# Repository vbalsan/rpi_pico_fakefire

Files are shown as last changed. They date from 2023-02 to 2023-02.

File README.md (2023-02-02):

# rpi_pico_fakefire

The electric fireplace project.

Main goal is to have this :
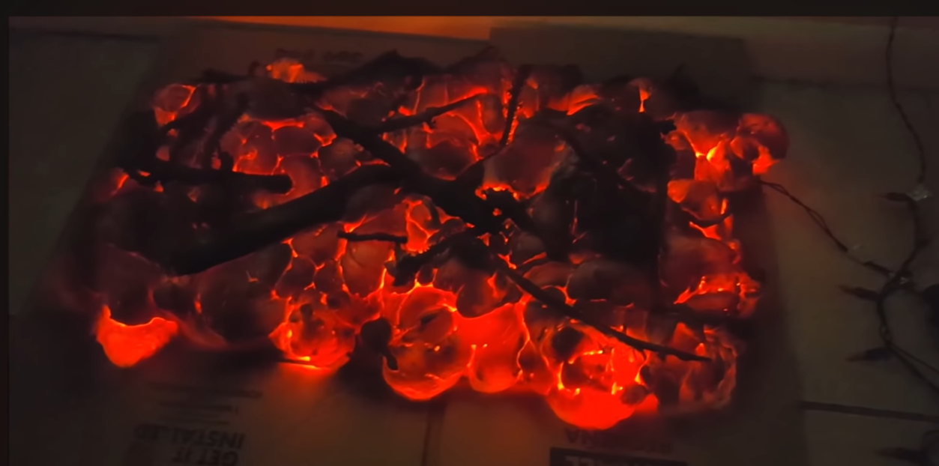
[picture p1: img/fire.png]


But with flickering, and sound, and little bonus like color control...
Idea came after landlord decided that we could not use our fireplace anymore, and didn't want to pay 400-500 bucks for an electric one.

## **How to ?**
The trick is to use foam (the kind you can find at reno store for filling cracks and holes) with lights, of course since just simple Christmas lights don't twinkle, we need to use a microcontroller with leds.

After several tests, I abandonned the idea of leds with PWM, for a led strip, much better, but the ws2812/ws2811 needs special timings.
Used ATtiny85 at the beginning since I had plenty, but the low-power 10MHz versions cannot manage the 800 or 400kHz ws2811 chips plus the calculation for the lights.

As I found, a raspberry pico is much better for the project, the PIOs can decipher IR reception without stopping the stream (a complete IR frame is around 40ms) , and I could write a PIO-assembly program to manage the lights within the main C file.
Could have gone with the rp2040 only, but for 4$...

## **What is there in the end ?**
Final board contains :
- a 12V / 5V converter, switching DC-DC
- a MOSFET to control 12V supply to the strip
- NAND gate for 3.3V to 5V conversion (could have done with diode)
- a DFPlayer for the sound
- a PAM8403 for amplification (not really necessary for one 4 Ohm speaker)
- TSOP1838B IR receiver
- a raspberry pico for all the logic
- a 4 Ohm speaker
- several old 5mm leds and through hole resistor for a retro look

## **Analysis for the signal controlling the ws2811 :**

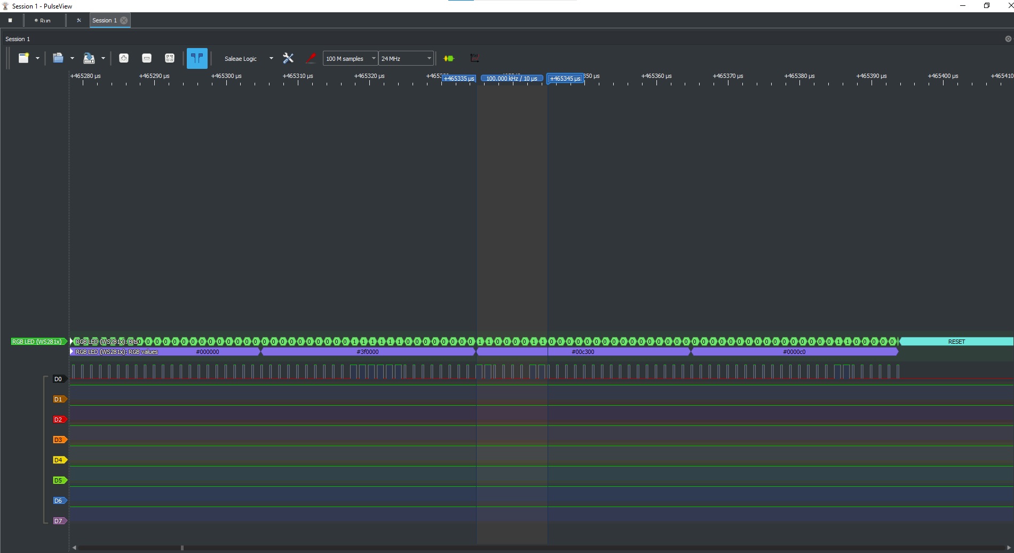
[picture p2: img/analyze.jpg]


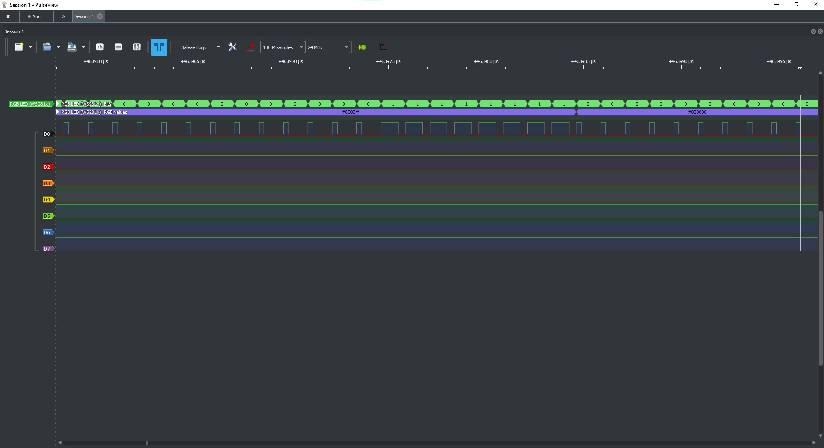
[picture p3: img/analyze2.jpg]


This gave me the occasion to create libraries for the IR receiver (TSOP1838B) and the ws2811.

## **The PCB :**
First prototype was on a... prototype board, but decided to go real PCB with Kicad and JLCPCB, result :

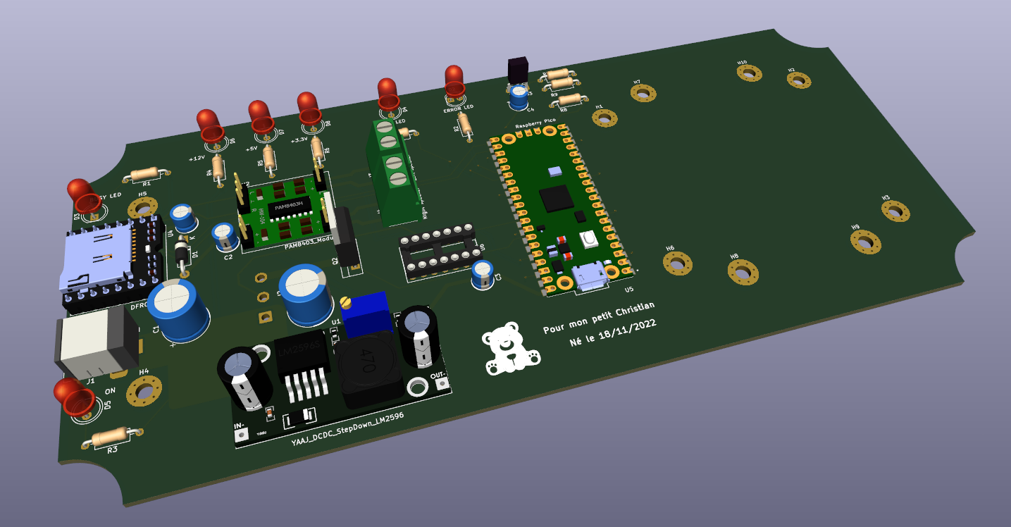
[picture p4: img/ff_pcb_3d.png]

PCB in 3D on Kicad

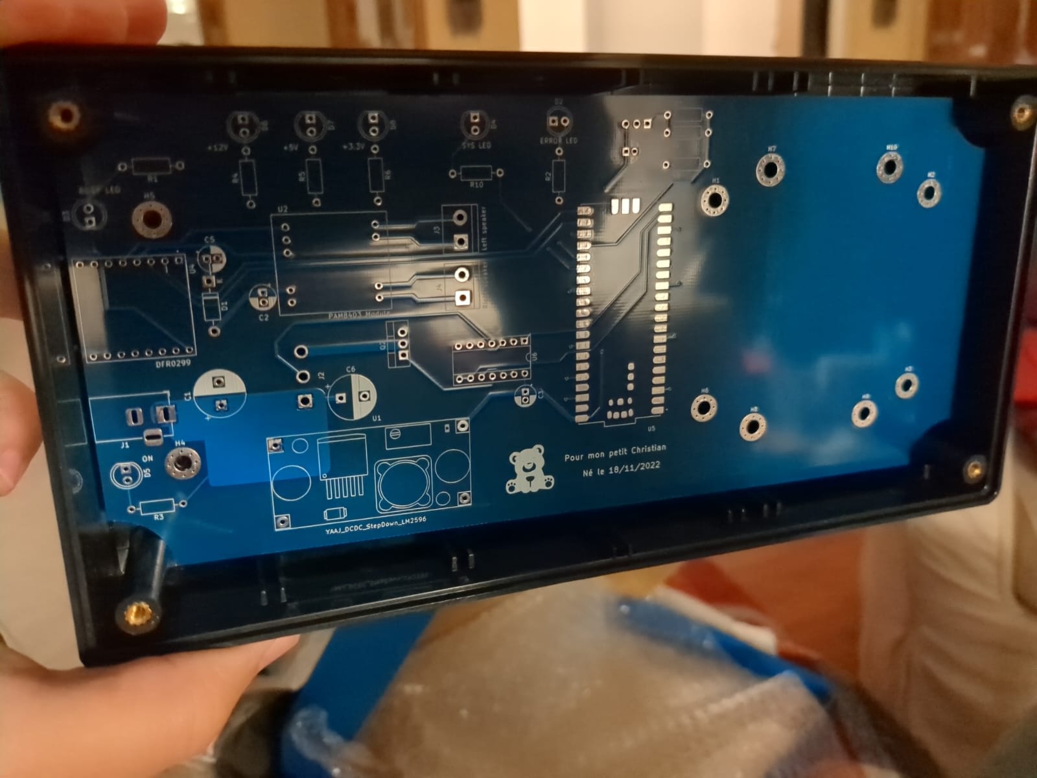
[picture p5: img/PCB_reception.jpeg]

PCB received

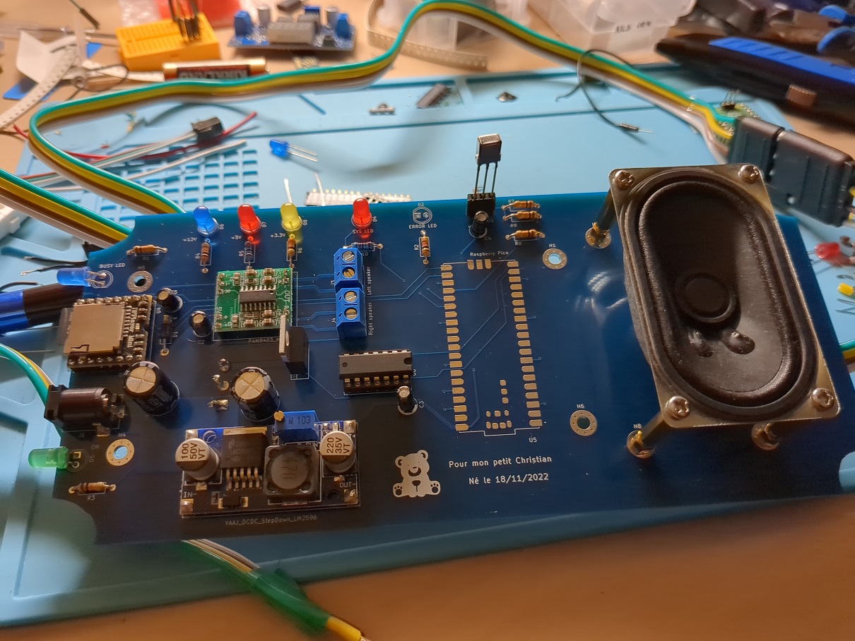
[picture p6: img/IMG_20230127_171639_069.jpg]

PCB almost fully populated

## **What now ?**
So far, project is continuing... There are issues on IR reception, probably using 3 resistors to decrease the voltage from 5V to 3.3 for GPIO was not a good idea.
Need to make some tests as I could not find the input impedance of the pico GPIO.

## **Pro/cons**

- I've put 16V capacitor for the 12V supply, it's bad, but it was what I had in my drawer
- Forgot to put a UART/serial port, quite a mess to debug even if I could use the SWD
- Didn't add filtering for the sound, not specialist in this, right now the cracking wood sound is more like frying oil.

## **Mapping buttons : **

on off (top)                    menu
BA45FF00                        B847FF00

Test            +               return
BB44FF00        BF40FF00        BC43FF00

<<              play            >>
F807FF00        EA15FF00        F609FF00

0               -               C
E916FF00        E619FF00        F20DFF00

1               2               3
F30CFF00        E718FF00        A15EFF00

4               5               6
F708FF00        E31CFF00        A55AFF00

7               8               9
BD42FF00        AD52FF00        B54AFF00

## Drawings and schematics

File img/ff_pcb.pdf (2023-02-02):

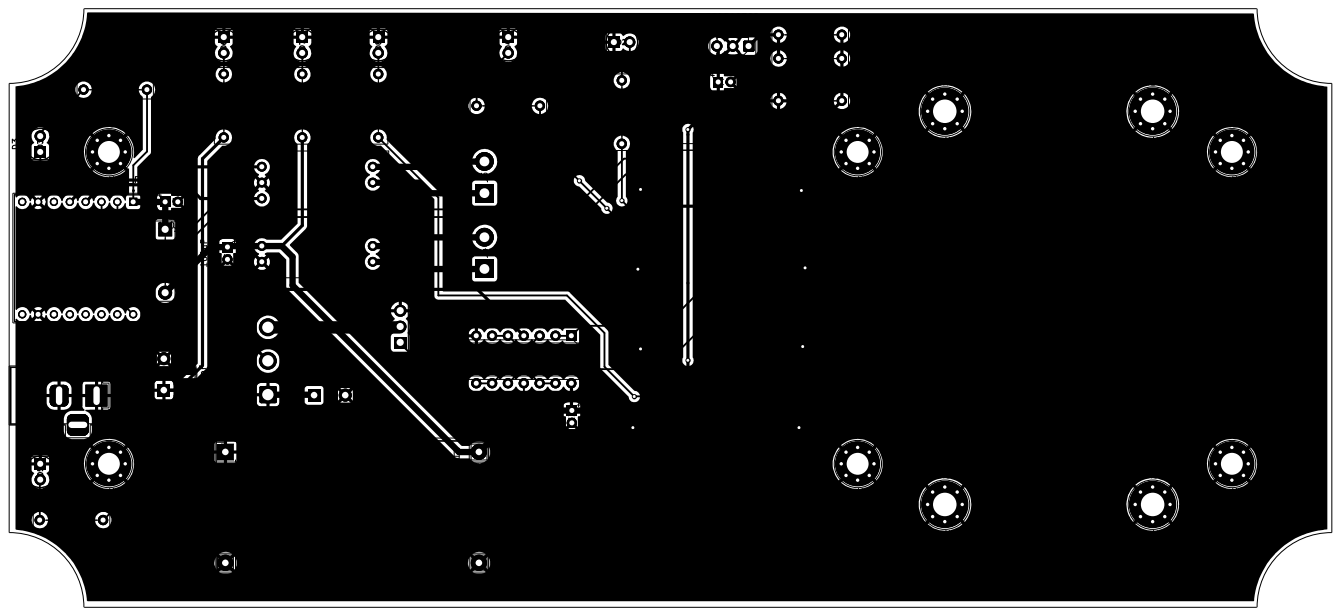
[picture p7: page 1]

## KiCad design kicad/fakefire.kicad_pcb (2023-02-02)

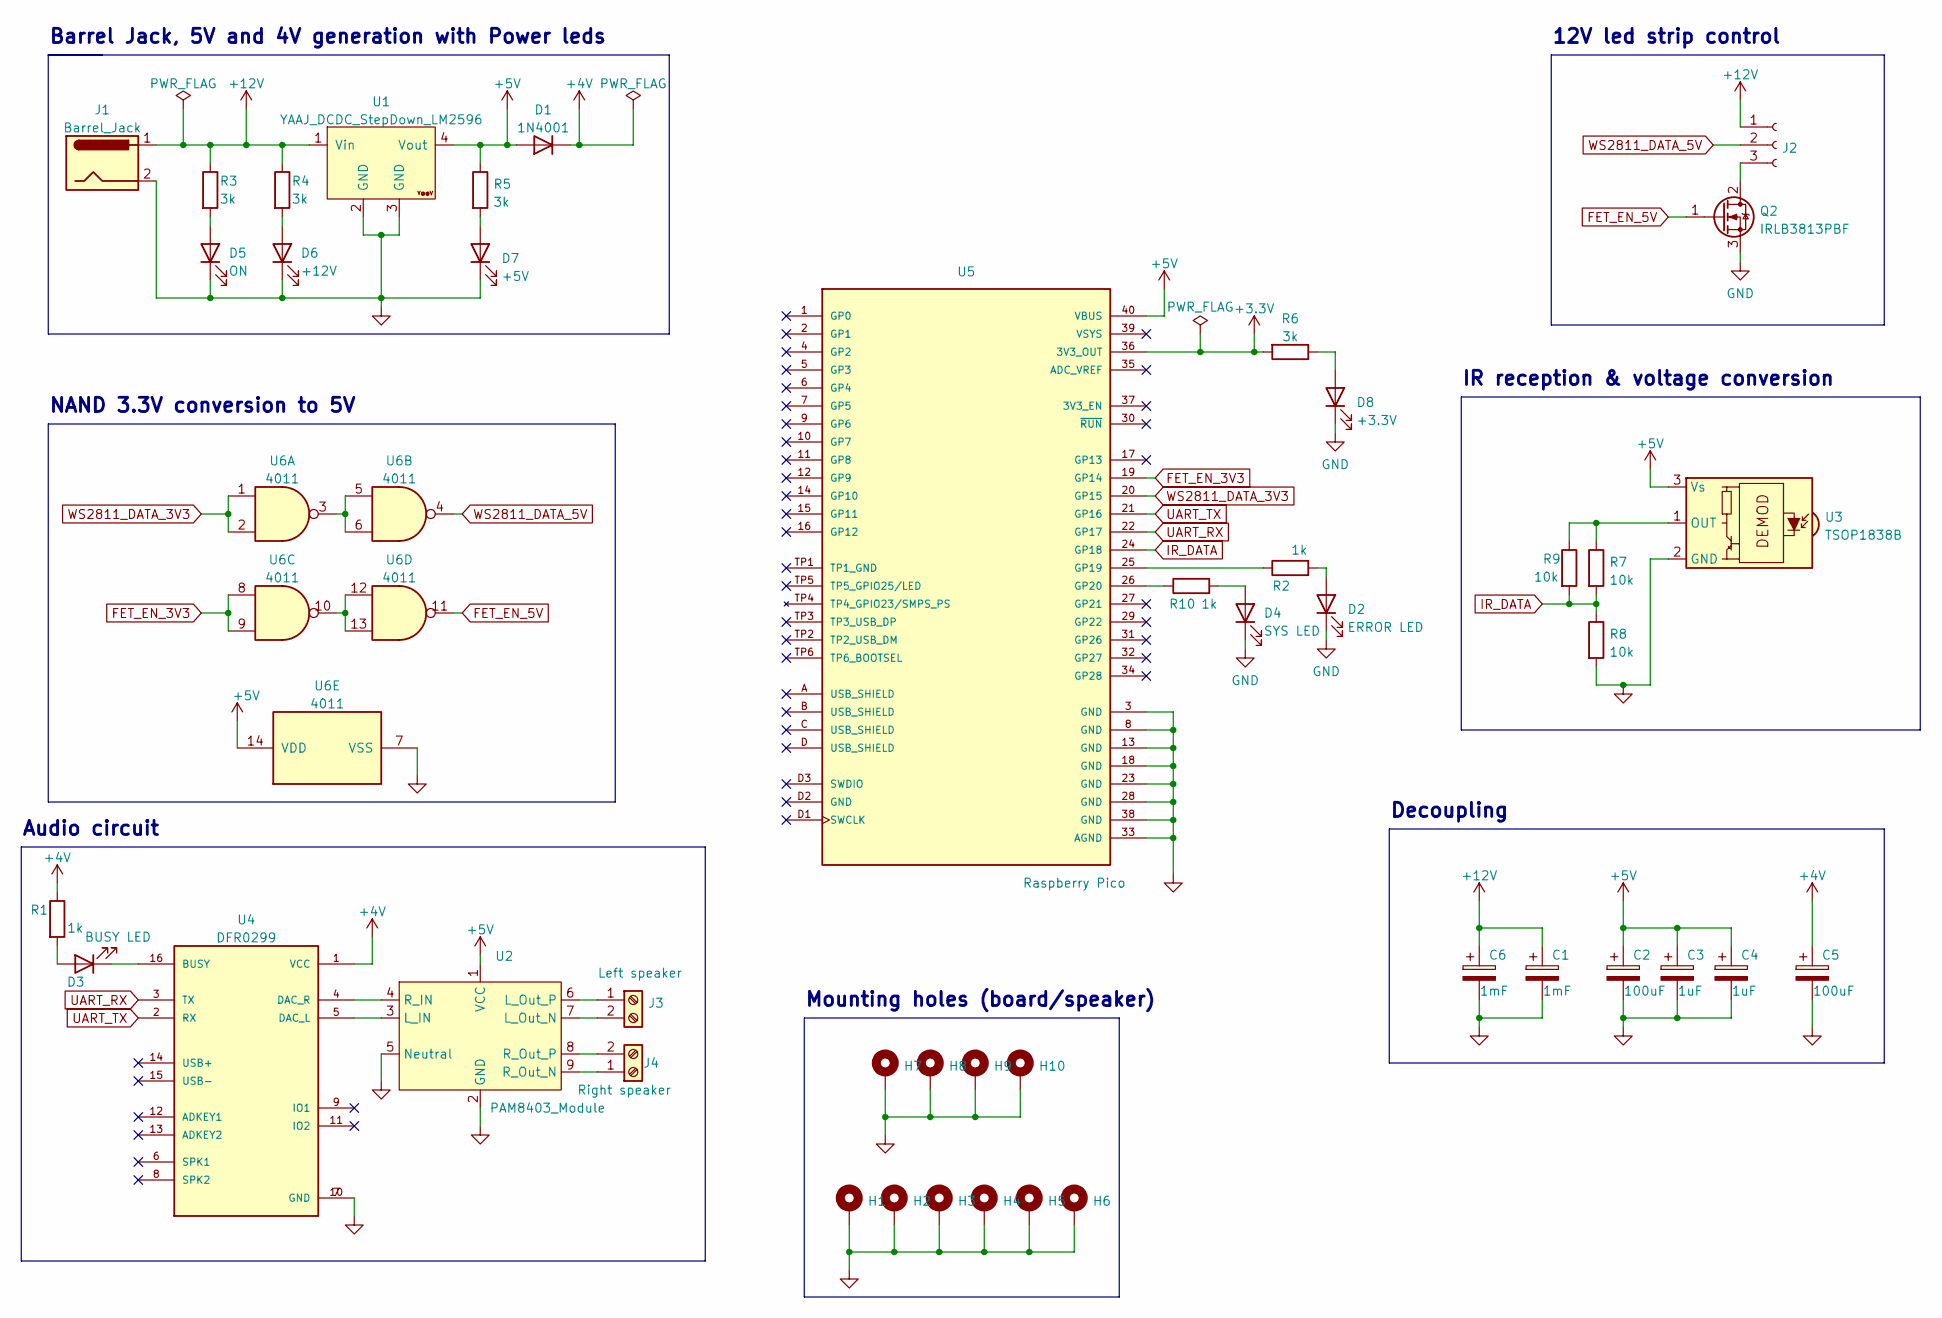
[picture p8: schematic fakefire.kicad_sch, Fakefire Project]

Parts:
C1, C6: 1mF; CP_Radial_D10.0mm_P5.00mm
C2, C5: 100uF; CP_Radial_D5.0mm_P2.00mm
C3, C4: 1uF; CP_Radial_D5.0mm_P2.00mm
D1: 1N4001; D_DO-41_SOD81_P10.16mm_Horizontal
D2: ERROR LED; LED_D5.0mm
D3: BUSY LED; LED_D5.0mm
D4: SYS LED; LED_D5.0mm
D5: ON; LED_D5.0mm
D6: +12V; LED_D5.0mm
D7: +5V; LED_D5.0mm
D8: +3.3V; LED_D5.0mm
H1, H2, H3, H4, H5, H6: MountingHole_Pad; MountingHole_3.5mm_Pad_Via
H7, H8, H9, H10: MountingHole_Pad; MountingHole_3.7mm_Pad_Via
J1: Barrel_Jack; BarrelJack_Horizontal
J2: Conn_01x03_Female; SolderWire-1sqmm_1x03_P5.4mm_D1.4mm_OD2.7mm
J3: Left speaker; TerminalBlock_bornier-2_P5.08mm
J4: Right speaker; TerminalBlock_bornier-2_P5.08mm
Q2: IRLB3813PBF; TO-220-3_Vertical
R1, R2, R10: 1k; R_Axial_DIN0207_L6.3mm_D2.5mm_P10.16mm_Horizontal
R3, R4, R5, R6: 3k; R_Axial_DIN0207_L6.3mm_D2.5mm_P10.16mm_Horizontal
R7, R8, R9: 10k; R_Axial_DIN0207_L6.3mm_D2.5mm_P10.16mm_Horizontal
U1: YAAJ_DCDC_StepDown_LM2596
U2: PAM8403_Module
U3: TSOP1838B; Vishay_MINICAST-3Pin
U4: DFR0299; MODULE_DFR0299
U5: Raspberry Pico; Pico; PARTREV 1.6
U6: 4011; DIP-14_W7.62mm_Socket

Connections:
+3.3V: R6.2, U5.36 (3V3_OUT)
+4V: C5.1, D1.1 (K), R1.1, U4.1 (VCC)
+5V: C2.1, C3.1, C4.1, D1.2 (A), R5.1, U1.4 (Vout), U2.1 (VCC), U3.3 (Vs), U5.40 (VBUS), U6.14 (VDD)
+12V: C1.1, C6.1, J1.1, J2.1, R3.1, R4.1, U1.1 (Vin)
FET_EN_3V3: U5.19 (GP14), U6.8, U6.9
FET_EN_5V: Q2.1 (G), U6.11
GND: C1.2, C2.2, C3.2, C4.2, C5.2, C6.2, D2.1 (K), D4.1 (K), D5.1 (K), D6.1 (K), D7.1 (K), D8.1 (K), H1.1, H2.1, H3.1, H4.1, H5.1, H6.1, H7.1, H8.1, H9.1, H10.1, J1.2, Q2.3 (S), R8.2, U1.2 (GND), U1.3 (GND), U2.2 (GND), U2.5 (Neutral), U3.2 (GND), U4.7 (GND), U4.10 (GND), U5.3 (GND), U5.8 (GND), U5.13 (GND), U5.18 (GND), U5.23 (GND), U5.28 (GND), U5.33 (AGND), U5.38 (GND), U6.7 (VSS)
IR_DATA: R7.2, R8.1, R9.2, U5.24 (GP18)
unnamed: D2.2 (A), R2.2
unnamed: D3.1 (K), U4.16 (BUSY)
unnamed: D3.2 (A), R1.2
unnamed: D4.2 (A), R10.2
unnamed: D5.2 (A), R3.2
unnamed: D6.2 (A), R4.2
unnamed: D7.2 (A), R5.2
unnamed: D8.2 (A), R6.1
unnamed: J2.3, Q2.2 (D)
unnamed: J3.1, U2.6 (L_Out_P)
unnamed: J3.2, U2.7 (L_Out_N)
unnamed: J4.1, U2.9 (R_Out_N)
unnamed: J4.2, U2.8 (R_Out_P)
unnamed: R2.1, U5.25 (GP19)
unnamed: R7.1, R9.1, U3.1 (OUT)
unnamed: U2.3 (L_IN), U4.5 (DAC_L)
unnamed: U2.4 (R_IN), U4.4 (DAC_R)
unnamed: R10.1, U5.26 (GP20)
unnamed: U6.3, U6.5, U6.6
unnamed: U6.10, U6.12, U6.13
UART_RX: U4.3 (TX), U5.22 (GP17)
UART_TX: U4.2 (RX), U5.21 (GP16)
WS2811_DATA_3V3: U5.20 (GP15), U6.1, U6.2
WS2811_DATA_5V: J2.2, U6.4

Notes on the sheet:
12V led strip control
IR reception & voltage conversion
Audio circuit
Barrel Jack, 5V and 4V generation with Power leds
Mounting holes (board/speaker)
Decoupling
NAND 3.3V conversion to 5V

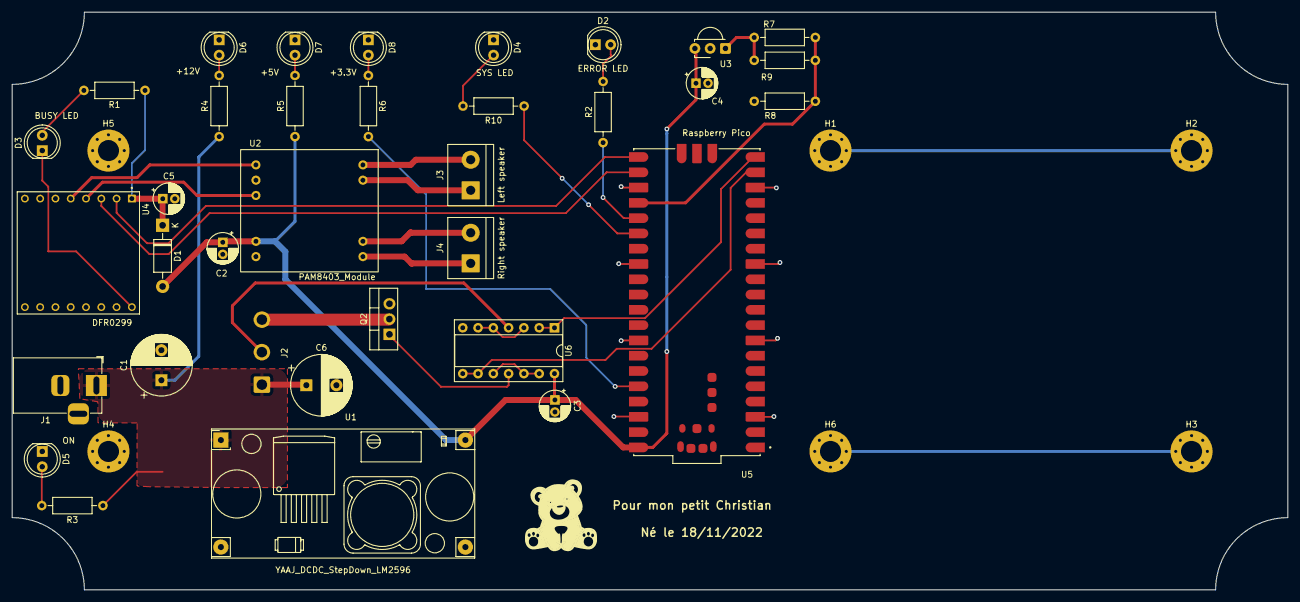
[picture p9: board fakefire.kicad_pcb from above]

Board: 2 copper layers, 212.0 x 96.0 mm, 41 parts (0 on the bottom side), 32 nets.

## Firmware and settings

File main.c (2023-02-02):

/**
 */


#include <stdio.h>
#include <stdlib.h>

#include "globals.h"
#include "values.h"

#include "pico/stdlib.h"

#include "nec_receive_library/nec_receive.h"
#include "DFPlayer_library/DFPlayerCommands.h"
#include "ws2811_library/ws2811.h"

uint8_t main_val   = 0;             // main_val is equal to the current value in array
uint8_t main_val10 = 0;             // same as main_val but divided by 10
uint8_t main_val50 = 0;             // same as main_val but divided by 50

uint8_t *pGreenVal;                 // Pointer to the value of green (can be full, /10 or /50)
uint8_t *pRedVal;                   // Pointer to the value of red (can be full, /10 or /50)
uint8_t *pBlueVal;                  // Pointer to the value of blue (can be full, /10 or /50)

void SetGreen()
{
    pRedVal = &main_val10;
    pGreenVal = &main_val;    
    pBlueVal = &main_val50;
}

void SetRed()
{
    pGreenVal = &main_val10;
    pRedVal = &main_val;    
    pBlueVal = &main_val50;
}

void SetBlue()
{
    pGreenVal = &main_val10;
    pBlueVal = &main_val;    
    pRedVal = &main_val50;
}

void set_power_leds(bool mosfet_val)  
{
    if (mosfet_val)
    {
        gpio_put(FET_PIN, 1);
    }
    else
    {
        for (uint8_t i = 0; i < NUM_PIXELS; i++) 
        {          
            put_pixel(0);
        }
        gpio_put(FET_PIN, 0);
    }
}


void process_rx_data(uint8_t rx_data)
{
    switch (rx_data)
    {
    case 0x45:                      // on off                        
        SysActive = !SysActive;

        if(SysActive)
        {
            gpio_put(SYSLED, 1);
            set_power_leds(true);   // turn on MOSFET
            sleep_ms(20);
            SetRed();
            DFP_Main_Start();            
        }
        else 
        {
            gpio_put(SYSLED, 0);
            set_power_leds(false);  // stop MOSFET
            DFP_Main_Stop();
        }        
        break;

    case 0x44:                      // Test
        SetGreen(); 
        DFP_PlayTrack(1,2);
        break;

    case 0x40:                      // +
        DFP_IncreaseVolume();
        break;

    case 0x19:                      // -
        DFP_DecreaseVolume();
        break;

    case 0x47:                      // menu
        break;

    case 0x07:                      // <<
        DFP_PreviousTrack();
        break;

    case 0x09:                      // >>
        DFP_NextTrack();
        break;

    case 0x43:                      // return
        break;
    case 0x0D:                      // C
        break;

    case 0x15:                      // play
        DFP_PlayOrPause();
        break;

    case 0x16:                      // 0
        SetRed();
        break;
    case 0x0C:                      // 1
        SetBlue();
        break;
    case 0x18:                      // 2
        SetGreen();
        break;
    case 0x5E:                      // 3
        SetRed();
        break;
    case 0x08:                      // 4
        SetRed();
        break;
    case 0x1C:                      // 5
        SetRed();
        break;
    case 0x5A:                      // 6
        SetRed();
        break;
    case 0x42:                      // 7
        SetRed();
        break;
    case 0x52:                      // 8
        SetRed();
        break;
    case 0x4A:                      // 9
        SetGreen(); 
        DFP_PlayTrack(1,3);
        break;
    
    default:
        break;
    }
}

void ir_receive_and_exec()
{
    uint32_t rx_frame;                          // For IR frame, 32 bits message    
    uint8_t  rx_address, rx_data;               // received IR data

    while (!is_fifo_empty())
    {
        rx_frame = get_message();
        if (nec_decode_frame(rx_frame, &rx_address, &rx_data)) 
        {
            if(rx_address == 0x00)
            {
                process_rx_data(rx_data);                        
            }
        } 
        else 
        {
            printf("\t received: %08x", rx_frame);
        }
    }
}

void adjust_light(uint8_t *main_val, uint8_t *main_val10, uint8_t *main_val50, uint8_t luminosity)
{
    uint16_t tempvar = 0;

    tempvar = (uint16_t)(*main_val * (luminosity + 1));
    *main_val = tempvar >> 8;

    tempvar = (uint16_t)(*main_val10 * (luminosity + 1));
    *main_val10 = tempvar >> 8;

    tempvar = (uint16_t)(*main_val50 * (luminosity + 1));
    *main_val50 = tempvar >> 8;
}


/***********************************************************************************************/
/***********************************************************************************************/
/***********************************************************************************************/
int main() 
{
    sleep_ms(3000);                            // Some time for peripherals to get ready
    gpio_init(FET_PIN);
    gpio_set_dir(FET_PIN, GPIO_OUT);
    
    SysActive  = true;                         // System is "off", trigger or not the MOSFET
    error_code = NO_ERROR;      
    set_power_leds(true);                      // MOSFET

    uart_on   = false;                          // flag for uart errors
    ws2811_on = false;                          // flag for leds errors    

    uint8_t main_idx = 0;                       // Index for main array of values    
    uint8_t luminosity = 0;

    pGreenVal   = &main_val10;                  //
    pRedVal     = &main_val;                    // Default assignation to red colour
    pBlueVal    = &main_val50;                  //

    uint32_t pixel;                             // 32 bits value passed to the PIO state machine

    gpio_init(PICO_DEFAULT_LED_PIN);
    gpio_set_dir(PICO_DEFAULT_LED_PIN, GPIO_OUT);

    
    
    gpio_init(SYSLED);
    gpio_set_dir(SYSLED, GPIO_OUT);
    gpio_put(SYSLED, 1);

    gpio_init(ERROR_LED);
    gpio_set_dir(ERROR_LED, GPIO_OUT);

    stdio_init_all();       

    Serial_init(UART_ID,                        //
                BAUD_RATE,                      // for serial
                UART_TX_PIN,                    //
                UART_RX_PIN);                   // 

    Leds_init(WS2811_PIO, WS2811_PIN);          // for leds       

    IR_init(IR_PIO, IR_GPIO);                   // for ir    


    DFP_Init();                                 // Initialization of DFPlayer
    sleep_ms(3000);
    DFP_SetVolume(0x00);                        // Volume at 0x00/0x30

/*****/
    sleep_ms(1000);
    SetRed();
    
    DFP_Main_Start();
    DFP_SetBass();
    DFP_SetVolume(0x30);

/*****/
    while (!error_code)                         // Main loop, if no error
    {
        /********* LOOP FOR OFF *********/
        while(!SysActive)                       // If system is off we check IR
        {            
            ir_receive_and_exec();            
            sleep_ms(100);
        }

        /********* LOOP FOR ON *********/
        while(SysActive)                        // If system is on
        {

            for (uint8_t i = 0; i < 3; i++) // Yellow
            {  
                uint8_t idx = main_idx + i;
                main_val   = yellow_array_dec[idx]; 
                main_val10 = main_val / 2u;
                main_val50 = main_val / 5u;

                if (luminosity != 0xFF)
                {
                    adjust_light(&main_val, &main_val10, &main_val50, luminosity);
                }

                pixel = ugrb_u32( *pGreenVal,  
                                  *pRedVal,  
                                  *pBlueVal);          
                put_pixel(pixel);
            }
            for (uint8_t i = 0; i < (NUM_PIXELS - 3); i++) // Red
            {  
                uint8_t idx = main_idx + i;
                main_val   = red_arr[idx]; 
                main_val10 = main_val / 16u;
                main_val50 = main_val / 64u;

                if (luminosity != 0xFF)
                {
                    adjust_light(&main_val, &main_val10, &main_val50, luminosity);
                }

                pixel = ugrb_u32( *pGreenVal,  
                                  *pRedVal,  
                                  *pBlueVal);          
                put_pixel(pixel);
            }
            
            main_idx++;
                   
            gpio_put(PICO_DEFAULT_LED_PIN, 0);
            sleep_ms(50);                       // make a break to lock the pixels        
            gpio_put(PICO_DEFAULT_LED_PIN, 1);
            
            ir_receive_and_exec();              // Check if remote has sent message

            if (luminosity != 0xFF)
            {
                luminosity++;
            }
        }
        luminosity = 0;
    }

    /**********************************/
    /** out of while, error happened **/
    /**********************************/
    if(uart_on)
    {

    }

    if(ws2811_on)
    {

    }

    while(1)
    {    
        switch (error_code)
        {
            case SM_WS2811:
                gpio_put(ERROR_LED, 1);
                sleep_ms(50);                       
                gpio_put(ERROR_LED, 0);
                
                break;

            case PROG_WS2811:
                break;

            case SM_IR:
                break;
            
            case PROG_IR:
                break;

            case UART:
                break;

            default:
                break;
        }
    }



}

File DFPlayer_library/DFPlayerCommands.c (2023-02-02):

#include "DFPlayerCommands.h"
#include "hardware/uart.h"


void Serial_init(uart_inst_t *uart_id, 
                uint32_t baudrate,
                uint8_t tx_pin,
                uint8_t rx_pin)
{
    uart_init(uart_id, baudrate);

    uart_set_format(uart_id, 8 , 1 , UART_PARITY_NONE);

    // Set the TX and RX pins by using the function select on the GPIO
    // Set datasheet for more information on function select
    gpio_set_function(tx_pin, GPIO_FUNC_UART);
    gpio_set_function(rx_pin, GPIO_FUNC_UART);

    uart_on = true;
}

void DFP_Init()
{
    DFP_Send(0x3F, 0x00, 0x00);       // Initialization
    sleep_ms(30);
    DFP_SelectSDCard();    
    DFP_DACStart(); 
}



void DFP_PlayTrack(uint8_t folder, uint8_t track)
{
    DFP_Send(0x0F,folder,track);
    sleep_ms(30);
    DFP_SingleRepeatStart();
}

void DFP_PlayOrPause()
{
    if(playback)
    {
        DFP_Send(0x0E,0x00, 0x00);
        sleep_ms(30);
        playback = false;
    }
    else
    {
        DFP_Send(0x0D,0x00, 0x00);
        sleep_ms(30);
        playback = true;
    }
}

void DFP_SetBass()
{
    DFP_Send(0x07,0x00,0x05);
    sleep_ms(30);
}

void DFP_Stop()
{
    DFP_Send(0x16,0x00,0x00);
    sleep_ms(30);
}

void DFP_SingleRepeatStart()
{
    DFP_Send(0x19,0x00,0x00);
    sleep_ms(30);
}

void DFP_SingleRepeatStop()
{
    DFP_Send(0x19,0x00,0x01);
    sleep_ms(30);
}

void DFP_DACStart()
{
    DFP_Send(0x1A,0x00,0x00);
    sleep_ms(30);
}

void DFP_DACStop()
{
    DFP_Send(0x1A,0x00,0x01);
    sleep_ms(30);
}

void DFP_SelectSDCard()
{
    DFP_Send(0x09,0x00,0x02);       
    sleep_ms(30);    
}

void DFP_SetSleepMode()
{
    DFP_Send(0x0A,0x00,0x00);       
    sleep_ms(30);    
}

void DFP_SetNormalMode()
{
    DFP_Send(0x0B,0x00,0x00);       
    sleep_ms(30);    
}

void DFP_Reset()
{
    DFP_Send(0x0C,0x00,0x00);       
    sleep_ms(30);    
}

// Well, there is a command increase/decrease soooo...
/*
void DFP_DecreaseVolume()
{
    if(main_volume >= 0x01)
    {
        DFP_Send(0x06,0x00,--main_volume);       
        sleep_ms(30);
    }
}

void DFP_IncreaseVolume()
{
    if(main_volume <= 0x2F)
    {
        DFP_Send(0x06,0x00,++main_volume);       
        sleep_ms(30);
    }    
}
*/
void DFP_DecreaseVolume()
{
    DFP_Send(0x05,0x00,0x00);       
    sleep_ms(30);    
}

void DFP_IncreaseVolume()
{
    DFP_Send(0x04,0x00,0x00);       
    sleep_ms(30);    
}

void DFP_PreviousTrack()
{
    DFP_Send(0x02,0x00,0x00);       
    sleep_ms(30);    
}

void DFP_NextTrack()
{
    DFP_Send(0x01,0x00,0x00);       
    sleep_ms(30);    
}

void DFP_SetVolume(uint8_t vol)
{
    if(vol <= 0x30)
    {
        DFP_Send(0x06,0x00,vol);       
        sleep_ms(30);
    }
    else
    {
        vol = 0x30;
        DFP_Send(0x06,0x00,0x30);   // Volume max
        sleep_ms(30);
    }
    //main_volume = vol;
}



uint8_t highByte(uint16_t value)
{
    return (value >> 8);
}
                            
uint8_t lowByte(uint16_t value)
{
    return (value & 0xFF);
}

void DFP_Send(uint8_t Command, uint8_t Par1, uint8_t Par2)
{   
  
  // Calculate the checksum (2 bytes)  
  uint16_t checksum = -(DFP_VER + DFP_LEN + Command + DFP_ACK + Par1 + Par2);

  // Build the command line  
  uint8_t Full_Command[10] = { DFP_START, 
                            DFP_VER, 
                            DFP_LEN, 
                            Command, 
                            DFP_ACK,
                            Par1, 
                            Par2, 
                            highByte(checksum), 
                            lowByte(checksum), 
                            DFP_END};
    
  for (uint8_t idx = 0; idx < 10; idx++)            // Send the command line to DFPlayer
  {
       uart_putc_raw(UART_ID, Full_Command[idx]);
  }
 }

void DFP_Main_Start()
{
    DFP_SelectSDCard();    
    DFP_SetVolume(0x20);
    DFP_PlayTrack(1,1);
    playback = true;
}

void DFP_Main_Stop()
{    
    DFP_SetVolume(0x00);                            
    DFP_Stop();
    playback = false;
    DFP_SetSleepMode();
}

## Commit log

2022-09-09 led ws2811 functional with PIO
2022-11-05 all leds working + better interface for libraries
2023-01-27 kicad pcb
    [fakefire.kicad_pcb, fakefire.kicad_sch, fakefire.sch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]
2023-02-02 update kicad files, added more infos, comments
    [fakefire.kicad_sch, fakefire_v2.kicad_pcb]
2023-02-02 Added debug functions, now it starts from power on
